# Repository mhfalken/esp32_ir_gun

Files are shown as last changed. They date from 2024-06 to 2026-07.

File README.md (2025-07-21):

# HomGuns - Laser Tag Guns
Here are my laser tag guns.  
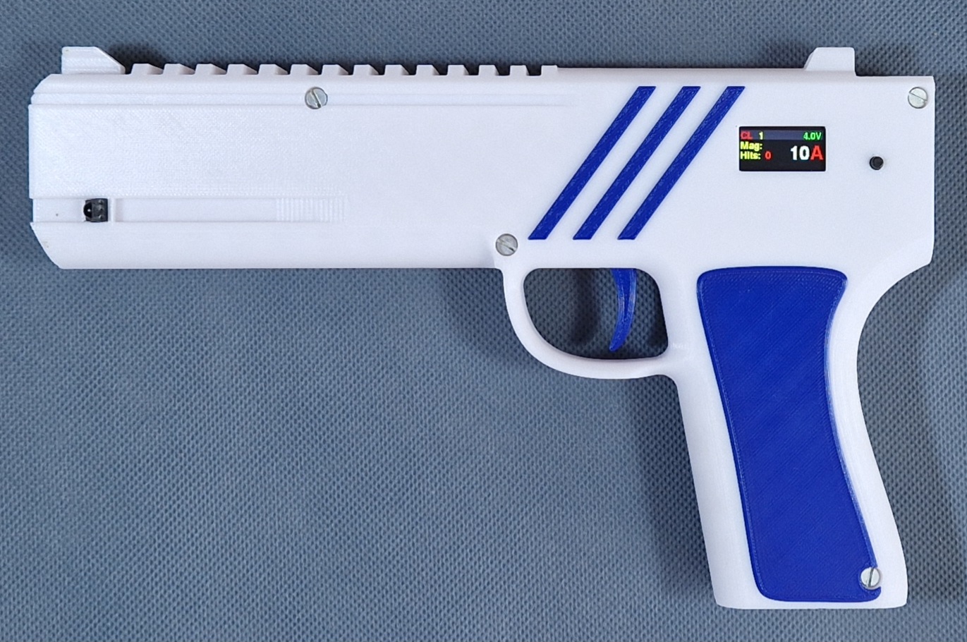
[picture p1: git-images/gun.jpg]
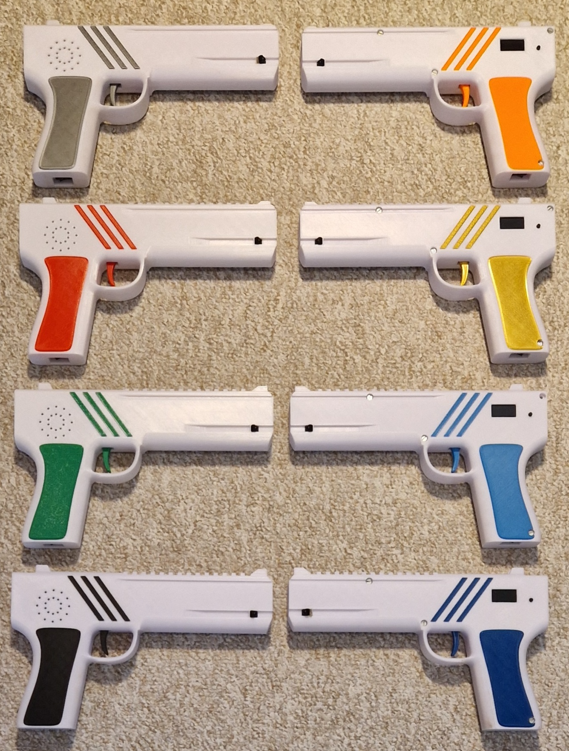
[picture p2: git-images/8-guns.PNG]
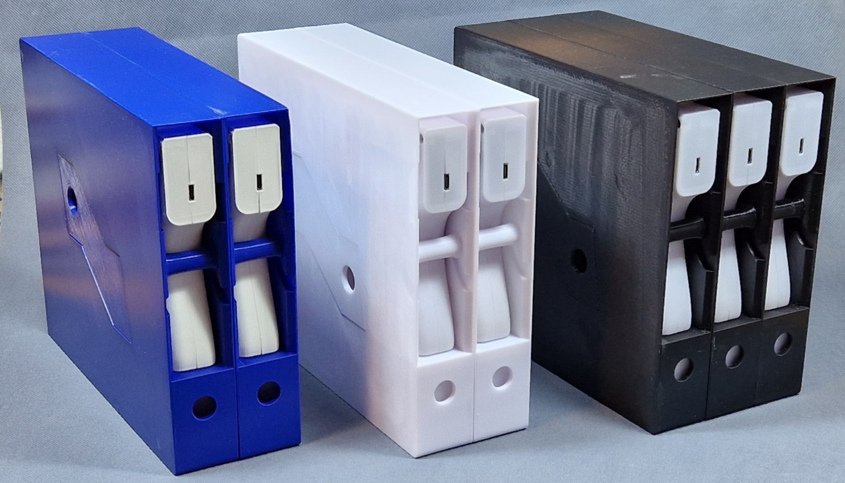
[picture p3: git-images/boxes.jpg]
  

They work both indoor and outdoor and are able to communicate with each other, so both the target and the shooter knowns when a person is hit.  
When the fight is over a complete battle statistic is available as a web page on the server gun.  
They are made completely from scratch, with a custom made PCB, Arduino programming and 3D print. They are self-contained so no vest is required and with a rechargeable battery.  
Upto 16 guns are supported at the same time.

## How to play
### Game mode (Connected mode)
1. (All guns must be in "WiFi" mode with one Server - see Configuration)
1. For each gun, select the team
1. Power on all guns (sequence doesn't matter). **The guns must not be powered off during the game and until the statistic is shown!**  
1. On the **Server gun**, enter configration and setup the game (see later)
1. Press short config button to toggle between **Game** screen and **Status** screen.
1. In **Game** screen: Long press config button to start the game (All guns says: **Get ready**)
1. (All guns are cleared and setup as the server gun, and all guns are locked until the pre-timer ends)
1. When the Pre-timer ends, then the gun vibrate and un-lock. The game is active. A game timer is shown on the display.
1. When the game timer ends, the gun says **Game over** and lock the gun.
1. When all have returned (are close to the server gun), then on the **Server** gun enter **Game** screen and long press to force update statistic from all guns.
1. Use a browser to connect to WiFi access point: **MH GUNS** and IP= **192.168.4.1** to see the complete status
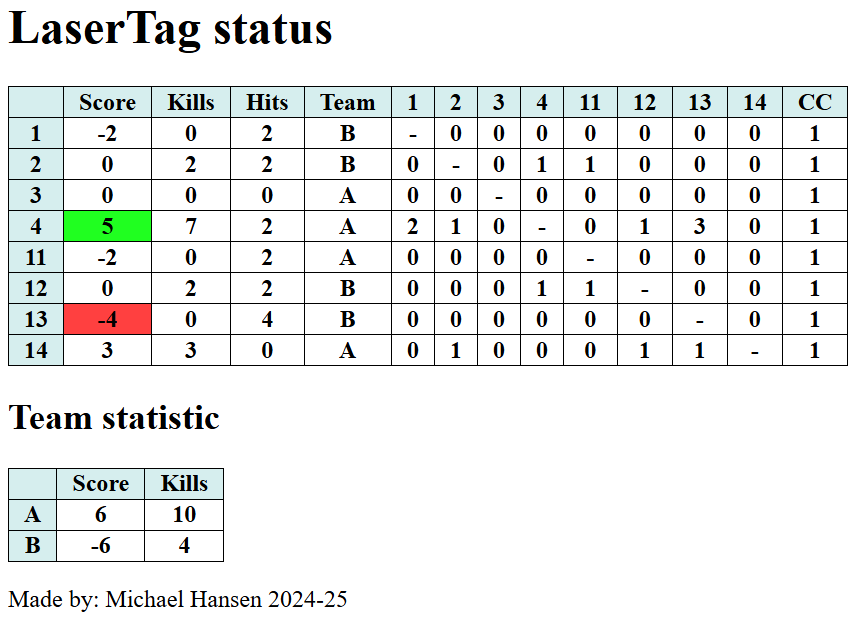
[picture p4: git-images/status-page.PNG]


Score is kills-hits. The green color marks the winner, red marks the gun (person) died.  
If a gun is powercycled during gameplay, then it is marked as red under CC and the statistic is not valid. (The reason is that part of the statistic is saved on each gun, which is lost if powered off.)  

### Old mode (no WiFi mode)
1. Setup all guns (see below)  
1. Power on all guns (sequence doesn't matter)  
1. Play - have fun  

### Advanced info
The person that shoot and hit first has the advantage - the killed person should escape.
- If hit, the gun is stunned - can't shoot for 2 sec, but can still be hit! (try to run away)
- If hit during stunned mode, the gun is disabled- can't shoot for 4 sec and can't be killed for 2 sec. (2 sec to run away)

The LCD display information is:  
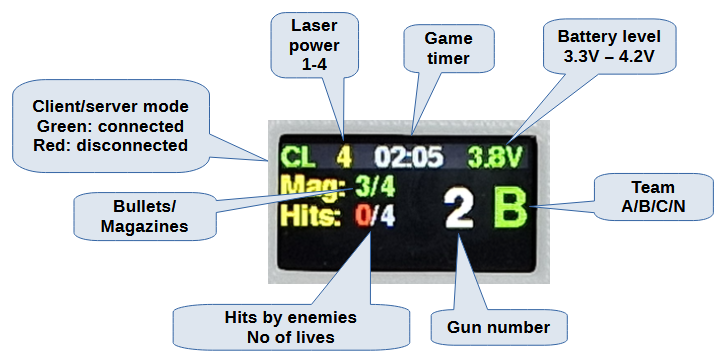
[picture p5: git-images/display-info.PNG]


## Configuration
### Change the configuration:  
You navigate with 
- Short press: next item
- Long press: enter/save item
The changes are automatic saved when the configuration is exited.

### Initial Configuration (setup)
Before the guns can be used for the first time, some configuration is needed.  
The initial configuration is entered by **holding down the configration button during power-up**.  
- Mode: TAG (TARGET is for other use)
- Each gun must have a **unique** gun id [1-16]
- If connected mode is used (recommended) then ONE gun must be **Server** and all the others must be **Clients**.
- Hardware options (LCD display)  

### Normal Configuration
The normal configuration is entered when the gun is powered on and then **long press the config button on the gun**  
- The IR power level must be set [1-4] 1: indoor, 4 outdoor
- Each gun must select a team (A, B, C or None (all against all))
- Sound: Level (Off, Low, Medium or High)
- Charge mode: Off, On (not required but makes a graph during charging)

## Connected mode
In connected mode the guns can communication with each other and at the end of play, the complete status of the game can be seen on a WEB page.  
When connected, the shooting gun will light green when it hits another gun.
- ONE gun is setup as a WiFi access point (server)
- All the other guns are setup as clients
- When end of game, on the **server** gun, enter **Game** screen and long press the config button to force all client to re-send all hit data in case some was lost during transmission.
- A simplified gamastatistic is shown on the server gun (long press to exit - WEB server doesn't work when this list is active)
- The server also have a build-in WEB page that can be access with a browser: SSID: MH GUNS, IP: 192.168.4.1

### Gamemodes
Can only be setup on the **server gun**.  

| Gamemode | Description |  
|---|---|
| Unlimited<br>(Standard) |This is the standard mode when the guns are powered on. Here you have unlimited bullets and unlimited hits (you can't die).|
| Combat | In this mode you have a **number of magazines** with 6 bullets in each. When a magazine is empty you need to press the button on the side of the gun to change to a new magazine. If the magazine is not empty, the rest of the bullets in the magazine is lost!<br>You have a **limited number of lives**, and when they are used you are dead (the gun doesn't work anymore).<br>Combat mode can only be selected on the master gun i.e. you need to be in connected mode and in game mode in order to use it.|

For both modes, there is a **Pre** timer (time to hide) and a **Play** timer (game lenght).  

## Charging
A fully charged gun can work for app. 3 hours.  
Power on the gun and then insert a cable connected to a charger into the USB-C plug. The status screen will change to charge mode (autodetected)  
It take app. 2 hours to completely charge the gun.  
***NB: The gun can NOT power it self OFF, so it is important that the gun is NOT left with power ON.***  
If not used for 6 minutes (and not in gamemode or charging mode) the gun will say 'Idle'.

## Standalone server module (optinal)
I have made a standalone server controller, so it is easier to control the guns. The hardware is a Cheap Yellow Display (CYD) module, which is an ESP32 with a 2.8" touch screen, that is described here: https://randomnerdtutorials.com/cheap-yellow-display-esp32-2432s028r/.   
To use it, just download the esp32_ir_gun_server software and it is ready to use. All the guns must be in **Client** mode.  
The module has a large touch screen, where all the options are present in a menu system. In this way it is easier to setup and control the guns.  
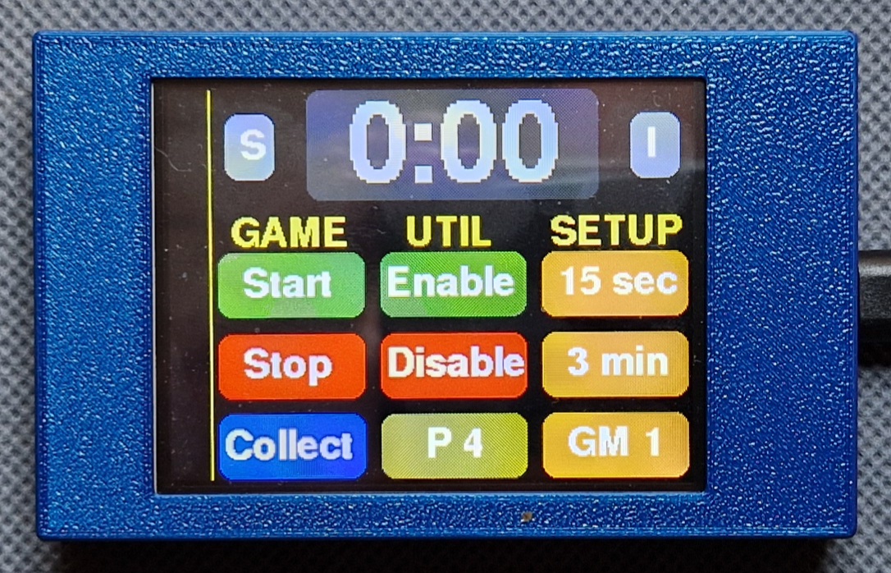
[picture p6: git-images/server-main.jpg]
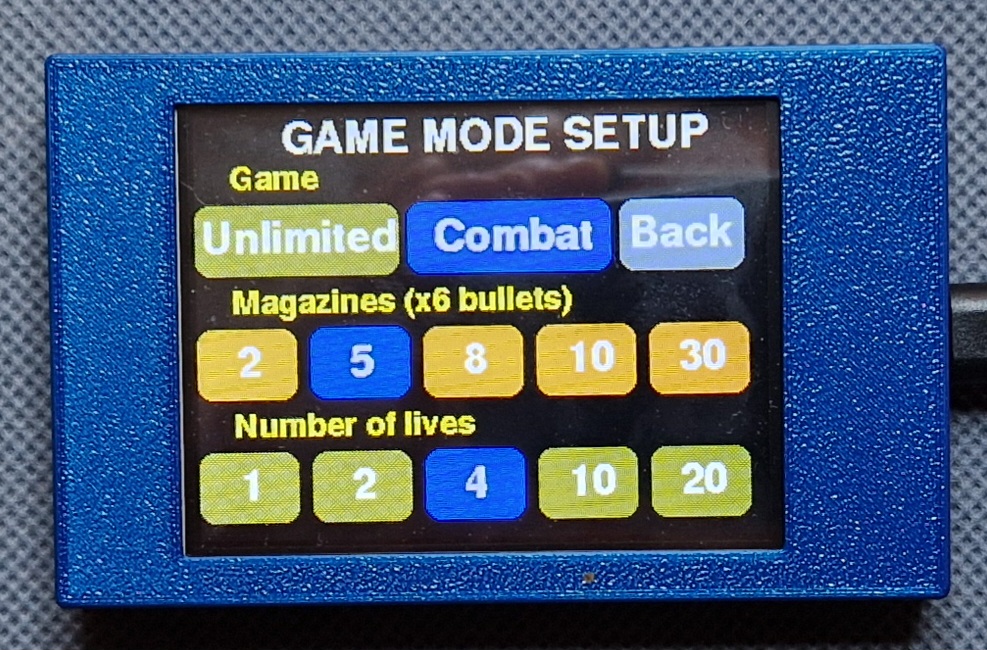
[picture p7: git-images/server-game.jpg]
 

## Firmware update

To update the GUN firmware, use the following link:
https://espressif.github.io/esptool-js/

Connect the GUN with a USB cable and press **Connect** in the GUI.  
The binary files are placed in **/bin** directory and must be entered as follow:  
| Flash Address | IR_GUN | IR_GUN_SERVER |
|---|---| -----|
|0x1000|esp32_ir_gun.ino.bootloader.bin|esp32_ir_gun_server.ino.bootloader.bin|
|0x8000|esp32_ir_gun.ino.partitions.bin|esp32_ir_gun_server.ino.partitions.bin|
|0xE000|boot_app0.bin|boot_app0.bin|
|0x10000|esp32_ir_gun.ino.bin|esp32_ir_gun_server.ino.bin|

Press **Add File** to get more entries. It should look like this:  
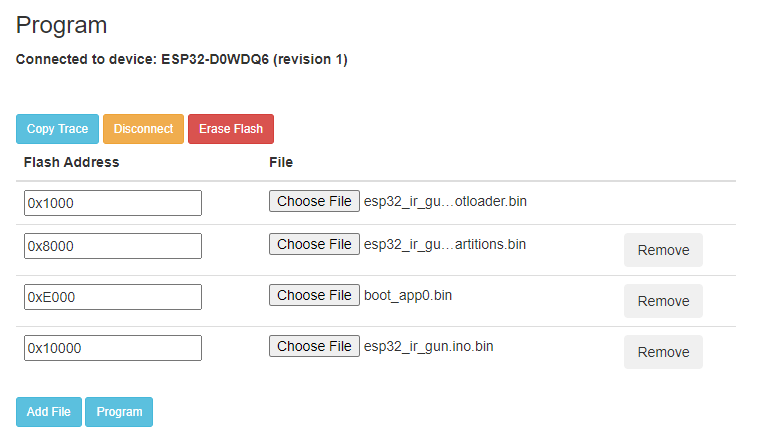
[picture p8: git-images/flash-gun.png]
  
To flash the GUN, press **Program**, and wait for the flashing to complete.  
Disconnect the GUN. The GUN firmware is now updated.

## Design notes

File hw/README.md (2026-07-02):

# Hardware overview

## Hardware components (for one gun)

| Count | Component | Info | Link (Aliexpress) |
|---|---|-----|--|
| 1| CPU board | ESP32 board Lolin32, USB-C | https://www.aliexpress.com/item/1005009137609466.html | 
| 1| Display | LCD 0.96" 80x160 | https://www.aliexpress.com/item/1005005300940624.html|
| 1| Amplifier board| PAM8302| https://www.aliexpress.com/item/32686733187.html|
| 2| IR receivers | TSOP32240 | https://www.aliexpress.com/item/1005012450128441.html|
| 1| IR transmitter | VSLY5940| https://www.aliexpress.com/item/1005005262125949.html|
| 1| Config button |6x6x10 | https://www.aliexpress.com/item/4001166999847.html|
| 1| Trigger button | 6x6x4.3| https://www.aliexpress.com/item/4001166999847.html|
| 5|NEO pixels | SMD 5050| https://www.aliexpress.com/item/1005002653014067.html|
|9| Resistors| SMD 0805 ||
|2|100-220uF| SMD C | https://www.aliexpress.com/item/1005005691643122.html |
|1|4.7uF | SMD 1206|
|1|1N5819ws | SMD 0805 / SOD 323 | https://www.aliexpress.com/item/1005003103906083.html|
|2| nFET | SI2302 or SI2300 SOT23 ||
|1| NPN | FMMT617 SOT23 ||
|1| Haptic feedback motor| 3.7V/16000 | https://www.aliexpress.com/item/1005009196829124.html |
|1|Speaker | diameter=36 mm| https://www.aliexpress.com/item/1005002939305602.html |
| 1|Power switch | 10x15 | https://www.aliexpress.com/item/1005005495319044.html|
| 1|Battery | Li-ion 14500 | |
|3| M3 screw | 6mm (PCB mount)| |
|1| M3 screw |  10 mm (trigger)| |
|4| M3 screw  | 20 mm (gun assembly)| |

0.5 m various single wires  
0.7 m servo wires (3 wires together)  
1x PCB  
1x 3D print  

## Tips
In generel look at the pictures in git-images, to see how it is supposed to look like.   
Remember the red wire shown on charger-wire.jpg. Without it, it won't work! (It is the only way to connect the battery to the CPU board without using the plug, which there is no room for.)  
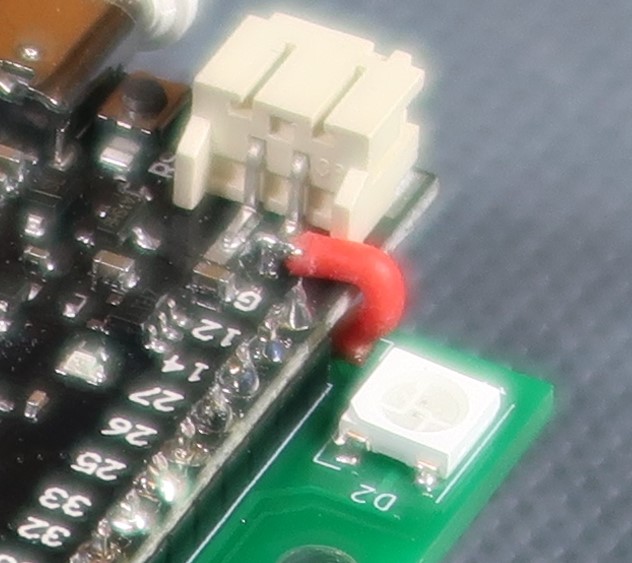
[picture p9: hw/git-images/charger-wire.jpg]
  

The last NEO pixel should be mounted in the tip of the gun and connected with wires to the main board.  
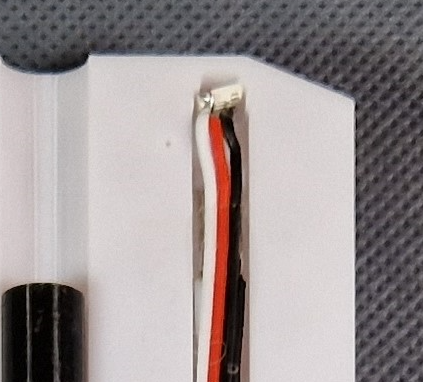
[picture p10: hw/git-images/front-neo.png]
  

It is a good idea to program the CPU board before mounting it. In this way it is very easy to check it is working when assempling it.  
Mount all the components on the PCB first, then mount the three add-on boards.

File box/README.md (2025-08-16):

# Storage box

I have made a box for two guns, that can be stacked together. There is a storage hole in the middle, that span all the boxes.

The STL file contain all the parts, but it is important to select the correct parts to make a box. The parts depend on the number of boxes.

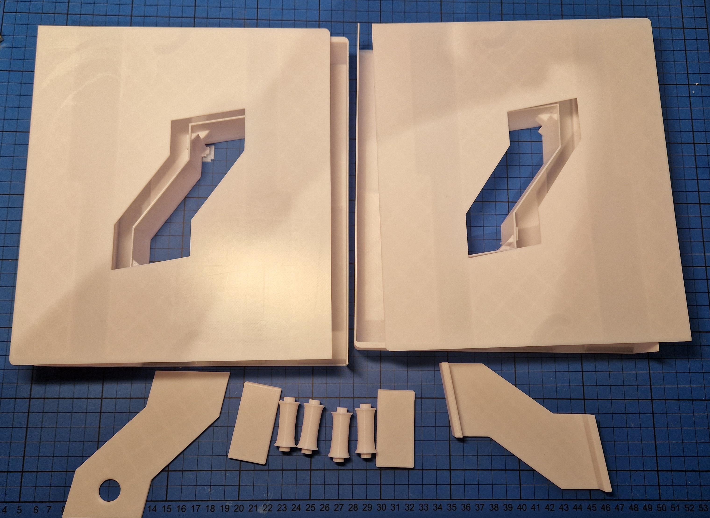
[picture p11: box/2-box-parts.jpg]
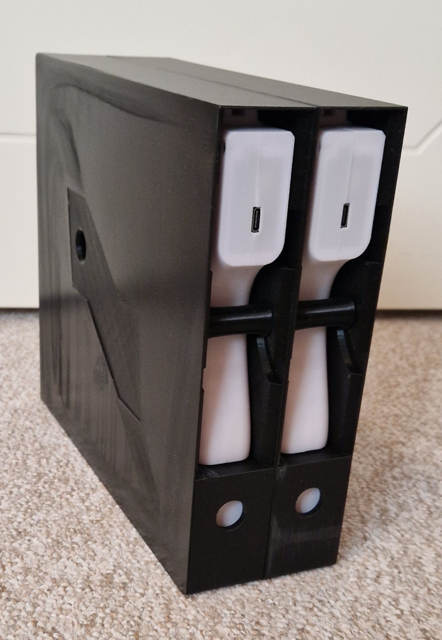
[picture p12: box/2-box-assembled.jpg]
  

Before a box is glued together, it is important to add the spring wire, as shown in this picture:

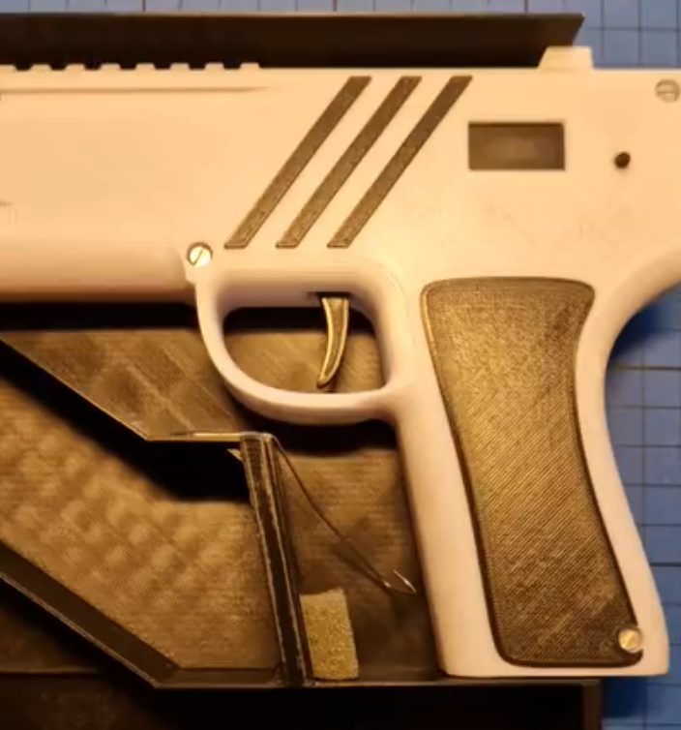
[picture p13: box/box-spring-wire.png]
 

Here is a short video, that demonstrates how it works:
https://github.com/mhfalken/esp32_ir_gun/tree/main/box/box-spring-wire.mp4

The spring wire I use is a piano wire of 0.80 mm. It is a bit of an art to bend the wire to fit the need. 
The foam part is added to make a better feel and to avoid that the guns rattles during transport. 

A box is glued together using cyanoacrylate.  
Boxes are stacked together using the inserts (no glue is needed).

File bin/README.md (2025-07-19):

# Software versions
It is always recommended that all guns are running the same version of the software.
| Version | Updated features |
| --- | --- |
| 1.31 | Better handling when guns/server is powered on/off<br>Better charge detection<br>Idle sound if not used for 4 minutes<br>The updated gamemode is **NOT backward compatible**! |
|2.10| Re-write communication. Support for 16 guns.<br>Idle sound >6 min<br>WEB layout updated<br>Server gun: display status list when game is over<br>New display layout<br>New gamemode: Combat mode |

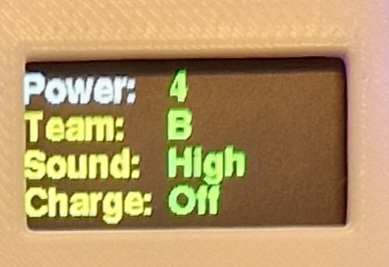
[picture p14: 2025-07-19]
git-images/gun-menu.jpg

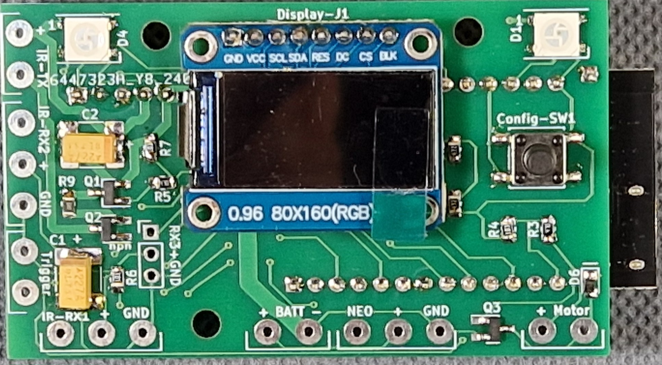
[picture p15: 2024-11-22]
hw/git-images/pcb-lcd.jpg

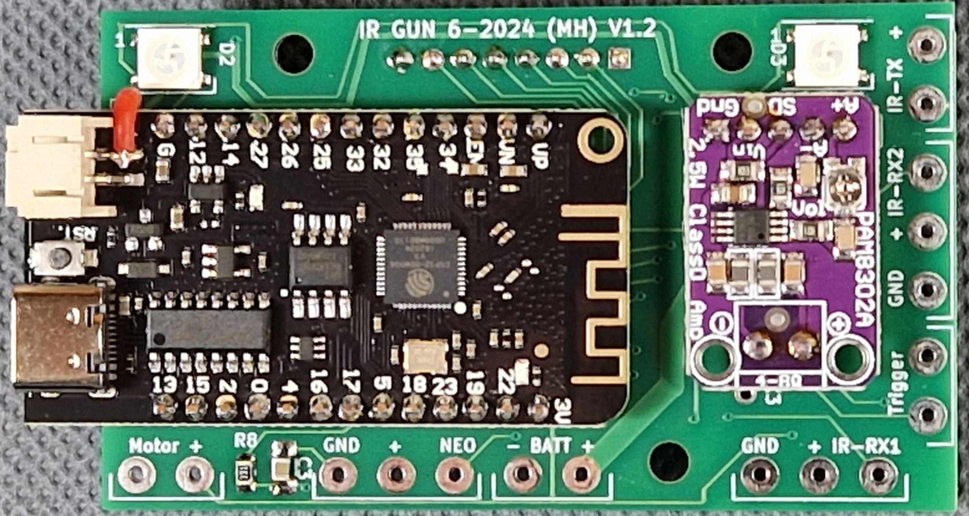
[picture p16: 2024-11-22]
hw/git-images/pcb-cpu.jpg

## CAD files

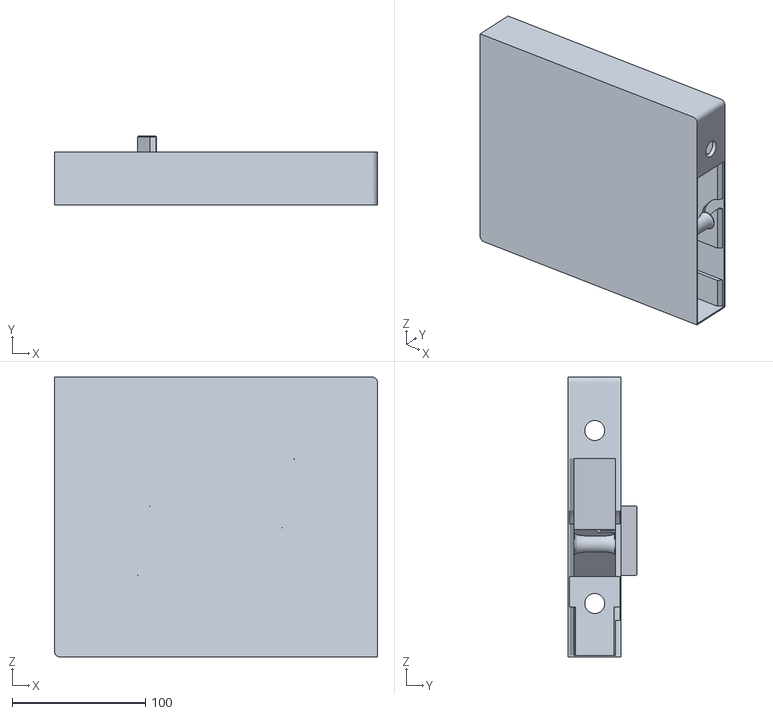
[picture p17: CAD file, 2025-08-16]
box/ir-gun-box.stl
242.0 x 51.6 x 209.6

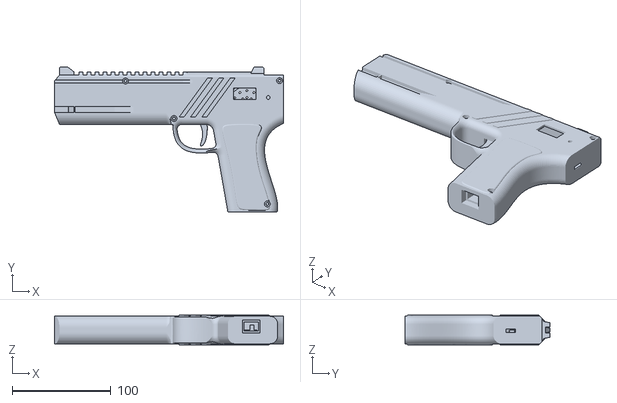
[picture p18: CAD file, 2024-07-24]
hw/ir-gun.stl
232.0 x 146.6 x 30.0

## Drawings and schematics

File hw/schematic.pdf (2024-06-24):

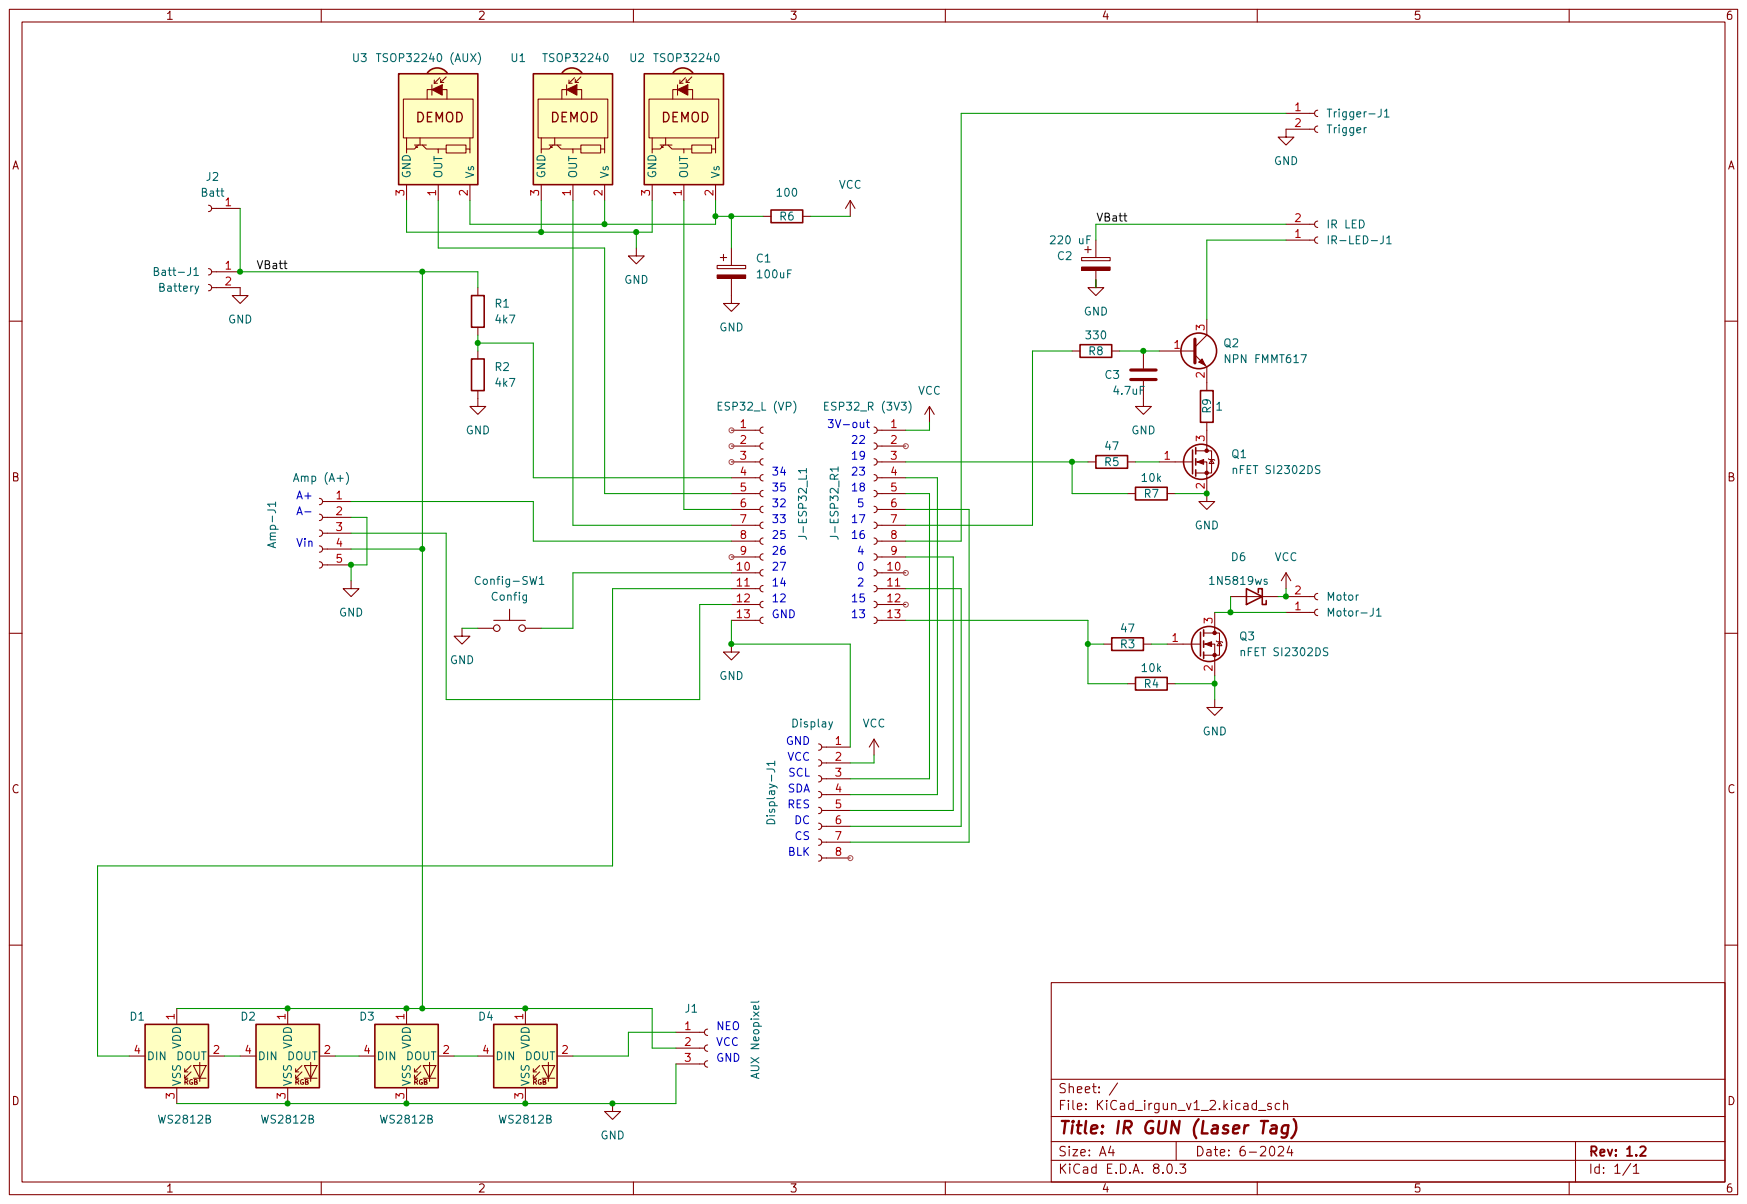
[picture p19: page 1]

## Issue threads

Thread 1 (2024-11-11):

Request for Source Code Access for ESP32 IR Gun Project

sam2024hanze, 2024-11-11:
Hello
I came across your ESP32 IR Gun project on GitHub, and I’m very impressed with the work you’ve done. I’m currently working on a similar project and believe that studying your source code could help me learn more about implementing IR communication and ESP32 programming.

Would it be possible for you to share the source code for this project? I fully understand if it’s not publicly available, but any guidance or insight would be greatly appreciated.

Thank you very much for your time and for sharing your project on GitHub.

mhfalken, 2024-11-11:
Hi
Currently I have no plan for sharing the source code. The ESP32 has hardware support for IR (partial), but their software is unstable (at least in the software version I am using), so it is not easy to give any guidance about how to use it, as I had to make some hacks to get it stable. This is a know problem with ESP32. The hardware implementation is also different between the various chip versions, which doesn't makes it easier!
/Michael

Closed 2024-11-12.

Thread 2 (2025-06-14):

Anmodning om KiCad-projektfiler til turnkey PCB-monteringsservice af ESP32 IR Gun

PipeSanktus, 2025-06-14:
Hej Michael,

Først og fremmest et stort tillykke med det fantastiske ESP32 IR Gun-projekt – din dokumentation og Gerber-filer er virkelig imponerende!

Jeg skriver fra Santiago i Chile, fordi jeg gerne vil bestille en turnkey PCB-monteringsservice hos en producent. Når SMD-komponenterne på overfladen er monteret automatisk, skal jeg kun lodde de større gennemgående komponenter manuelt for et sjovt projekt sammen med mine nevøer.

Desværre har jeg ikke KiCad-projektfilerne (.kicad_pro, .kicad_sch, .kicad_pcb), der er nødvendige for automatisk at generere BOM- og Pick-and-Place-filerne. Vil du være venlig at dele eller uploade hele KiCad-mappen under hw/? Med de filer kan jeg eksportere bom.csv og top-pos.csv på få sekunder og sende dem til producenten uden problemer.

Hvis der også er en måde, jeg kan støtte dit arbejde på (donationer, Patreon, teknisk feedback osv.), så sig endelig til – det ville være en ære at bidrage!

Tusind tak for din tid og for at dele så et fremragende projekt.

Venlig hilsen,
Felipe Sánchez

mhfalken, 2025-06-15:
I have sent the requested files to you.
/Michael

PipeSanktus, 2025-07-17:
Thank you very much for the file! I’ve now rolled up my sleeves and started
working on the project, but I realized I’m missing the 1N5819WS in 0805.
I’ve been searching everywhere but can’t seem to find it. Do you have any
recommendations for a good replacement or alternative?

El dom, 15 de jun de 2025, 4:05 a.m., Michael Hansen <
***@***.***> escribió:

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

mhfalken, 2025-07-18:
Well, the footprint SOD 323 will fit the footprint - I have update the description and fixed the link. Hope that will solve it.

Closed 2025-06-15.

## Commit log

2024-03-16 Fix sound issue when using new versions of board/lib files
2024-05-27 Display update speed enhanced
    Display speed enhanced by more than 10 times
    Auto charge detect mode updated
2024-06-24 New files
    [ir-gun.stl]
2024-07-24 Minor changes
    [ir-gun.stl]
2024-11-22 Minor resistor fix
2024-11-22 PCB version 1.2
2025-07-18 Minor footprint update
2025-08-16 Storage box
    [ir-gun-box.stl]
2026-07-02 Fix some of the links
    Updated links for CPU board, IR receivers, and haptic feedback motor.
2026-07-02 Add USB-C detail to CPU board in README
    Updated CPU board info to include USB-C.
2026-07-02 Update CPU board description in README
